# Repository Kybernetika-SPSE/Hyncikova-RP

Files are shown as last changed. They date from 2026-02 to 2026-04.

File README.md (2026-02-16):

<h1>Automatický krmič</h1><br>
<h2>Zařízení složící k pravidelnému dávkování krmiva</h2><br>
Systém kombinuje automatický režim s možností ručního ovládání pomocí tlačítek. Uživatel může ovlivnit chování zařízení podle aktuální potřeby. Během aktivního dávkování je chod signalizován LED diodou.<br>
Projekt je navržen jako základ, který lze dál upravovat a rozšiřovat podle konkrétních požadavků.<br>

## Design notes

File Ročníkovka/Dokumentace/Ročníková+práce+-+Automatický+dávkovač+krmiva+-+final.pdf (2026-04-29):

### Vyšší odborná škola a Střední průmyslová škola elektrotechnická Plzeň, Koterovská 85

## DLOUHODOBÁ ROČNÍKOVÁ PRÁCE S OBHAJOBOU

Téma: | Automatický dávkovač krmení (granulí) pro kočky
Autor práce: | Eliška HYNČÍKOVÁ
Třída: | 3. L
Vedoucí práce: | Jiří ŠVIHLA
Dne: | 30. 4. 2026

Hodnocení:

Prohlášení

Prohlašuji, že jsem tuto ročníkovou práci zpracovala samostatně a použila prameny, které uvádím v seznamu použité literatury a zdrojů informací.

Prohlašuji, že jsem nástroje UI využívala v souladu s principy akademické integrity a že na využití těchto nástrojů v práci vhodným způsobem odkazuji.

Souhlasím s využitím mé práce učiteli VOŠ a SPŠE Plzeň k výuce.

V Holýšově dne: |
Podpis: |

Poděkování

Ráda bych tímto poděkovala vedoucímu své ročníkové práce za odborné vedení, cenné rady a připomínky, které mi během zpracování práce poskytoval. Dále děkuji všem pedagogům, kteří mi v průběhu studia předávali své znalosti a podporovali mě při řešení technických i teoretických problémů.

Zvláštní poděkování patří mé rodině za trpělivost, podporu a zázemí, které mi umožnily věnovat se této práci. V neposlední řadě děkuji také všem, kteří mi jakýmkoli způsobem pomohli při realizaci projektu a přispěli k úspěšnému dokončení této ročníkové práce.

Anotace

Tato práce popisuje návrh a realizaci automatického dávkovače krmení pro kočky, který umožňuje časově řízené dávkování granulí a využívá ultrazvukový senzor k odhadu míry naplnění misky. Součástí je návrh mechaniky dávkovacího mechanismu, elektroniky s mikrokontrolérem, firmware pro plánování dávek a zpracování měření, kalibrace senzoru a experimentální ověření přesnosti i spolehlivosti zařízení.

Klíčová slova: dávkovač, kočka, ultrazvukový senzor, plánování dávek, mikrokontrolér, kybernetika

Abstract

This thesis describes the design and implementation of an automatic cat feeding dispenser that enables time-controlled dispensing of dry food and uses an ultrasonic sensor to estimate the level of food in the bowl. The work includes the design of the mechanical dispensing mechanism, the electronic system with a microcontroller, firmware for feed scheduling and measurement processing, sensor calibration, and experimental verification of the accuracy and reliability of the device.

Keywords: dispenser, cat, ultrasonic sensor, feed scheduling, microcontroller, cybernetics

Obsah

Úvod

Chov kočky domácí je v dnešní době velmi rozšířený, a to zejména v městském prostředí, kde se tento druh zvířete těší oblibě díky své relativní samostatnosti a nenáročnosti na prostor. Přesto však vyžaduje kočka pravidelnou péči, jejíž nedílnou součástí je správné a vyvážené krmení. Nedostatečná nebo naopak nadměrná dávka potravy může dlouhodobě vést ke zdravotním problémům, jako je obezita, podvýživa nebo poruchy trávení. Z těchto důvodů je důležité nejen dodržovat vhodné složení krmiva, ale také kontrolovat jeho množství a pravidelnost podávání. [1]

V současné uspěchané době však majitelé domácích mazlíčků často nemají možnost zajistit krmení v přesně stanovených časech, například z důvodu pracovního vytížení nebo delší nepřítomnosti. Jedním z možných řešení této problematiky je využití automatických dávkovačů krmiva.

Cílem této práce je proto navrhnout a zkonstruovat cenově dostupný, spolehlivý a funkční automatický dávkovač krmení pro kočku domácí. Navržené zařízení bude schopno dávkovat krmivo v předem nastavených časových intervalech a zároveň pomocí ultrazvukového senzoru odhadovat míru naplnění misky. Na základě naměřených hodnot bude systém vyhodnocovat, zda je nutné potravu ze zásobníku doplnit, nebo zda je miska stále dostatečně naplněna. Pokud měření prokáže, že kočka krmivo neodebrala v požadovaném množství, mechanismus doplnění se nespustí, čímž se zamezí zbytečnému plýtvání krmivem a přetěžování zařízení.

Práce je rozdělena na teoretickou a praktickou část. Teoretická část se zabývá principem ultrazvukového měření vzdálenosti, možnostmi dávkovacích mechanismů a základními zásadami časového řízení v automatizovaných systémech. Praktická část je zaměřena na samotný návrh řešení, konstrukci prototypu, jeho programování a následné testování funkčnosti v reálných podmínkách.

Pro výrobu byl sestaven časový plán prací Tabulka 1: Časový plán, aby samotná konstrukce a

ladění systému včetně zpracování dokumentace byla dokončena v daném termínu.

### 1. Teoretická část

Kybernetika se zaměřuje na řízení a přenos informací v systémech. Pro dávkovač krmení je klíčový uzavřený řídicí okruh: aktuátor (dávkovací mechanismus) → prostředí (granule v misce) → senzor (ultrazvuk) → měření času (RTC hodiny reálného času) →řídicí algoritmus, který dle změřeného stavu rozhoduje o dalším chování systému. [1]

Běžné konstrukce zahrnují šnekový dopravník, rotační komoru (klapku) nebo servo-řízení posuvné záklopky. Volba mechanismu ovlivňuje přesnost dávkování, riziko ucpání i nároky na napájení. Pro domácí dávkovač je vhodná rotační komora nebo šnek s krokovým motorem; pro jednodušší řešení postačí servo s dávkovací vrtulí. [1]

Ultrazvukový senzor (např. HC‑SR04/JSN‑SR04T) měří dobu letu zvukové vlny a umožňuje určit vzdálenost ke hladině granulí. Při měření v misce je nutné brát v úvahu minimální měřicí vzdálenost, kužel vyzařování a odrazy od stěn misky. Kalibrace zahrnuje mapování vzdálenosti na procento zaplnění pro konkrétní geometrii misky.

Časové dávkování lze realizovat pomocí reálného času (RTC modul, např. DS3231) nebo vnitřních

hodin mikrokontroléru. Plánování zahrnuje nastavení času, počtu dávek za den, velikosti dávky a podmínek, kdy se dávka přeskočí (např. je-li miska již plná). [3]

Konstrukce musí zamezit zranění zvířete (zakrytování pohyblivých částí), kontaminaci krmiva a zároveň umožnit snadné čištění. Elektronika má být chráněna proti prachu a granulím; napájení musí být bezpečné a spolehlivé.

### 1.1 Časový plán realizace projektu

Tabulka 1: Časový plán

Období | Plánované činnosti
listopad | Přípravná a analytická fáze • seznámení s tématem ročníkové práce, • stanovení hlavních cílů projektu, • rešerše existujících řešení automatických dávkovačů krmiva • studium principů automatizace, senzorů a časového řízení
prosinec | Návrh systému a volba součástek • návrh celkové koncepce zařízení • volba elektronických součástek • vytvoření schématu zapojení
leden | Návrh mechanických částí • tvorba 3D modelů jednotlivých mechanických částí zařízen
únor | Výroba prototypu, programování řídícího systému • příprava dat pro 3D tisk, výroba jednotlivých dílů • kontrola rozměrů a případné úpravy modelů na základě jejich funkčnosti • vytvoření řídicího programu pro mikrokontrolér
březen | Montáž zařízení a zapojení elektroniky • sestavení mechanických částí zařízení • zapojení elektronických komponent • kontrola správnosti zapojení,základní funkční testy • implementace časového řízení dávkování • práce se senzory a ladění softwaru
duben | Testování a úpravy prototypu, zpracování dokumentace a vychodnocení • testování funkčnosti zařízení v reálných podmínkách • kalibrace dávkování • odstraňování zjištěných nedostatků a zvyšování spolehlivosti zařízení • zpracování textové části ročníkové práce • doplnění obrazové dokumentace, závěrečné vyhodnocení projektu • příprava k obhajobě

### 1.2 Použité součástky a principy jejich fungování

V projektu byl jako hlavní řídicí jednotka použit mikrokontrolér Arduino Nano (viz Obrázek 1), který zajišťuje zpracování programu a řízení všech připojených komponent. Arduino vyhodnocuje vstupní data ze senzorů a na jejich základě ovládá výstupní zařízení, jako je servomotor a LED dioda. [5]

Pro sledování aktuálního času byl použit modul reálného času DS3231 RTC Module (viz Obrázek 2). Tento modul obsahuje vlastní záložní baterii, díky které si uchovává přesný čas i při odpojení napájení. V projektu slouží k tomu, aby bylo možné spouštět servomotor v pravidelných časových intervalech. [3]

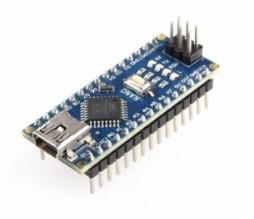
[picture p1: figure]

Obrázek 1: Mikrokontrolér Arduino Nano | Obrázek 2: Modul reálného času DS3231 RTC

K měření vzdálenosti byl použit ultrazvukový senzor HC-SR04 Ultrasonic Sensor (viz Obrázek 3).

Tento senzor pracuje na principu vysílání a přijímání ultrazvukových vln, ze kterých vypočítává

vzdálenost překážky. V rámci projektu plní bezpečnostní funkci – pokud je před senzorem

detekována překážka ve vzdálenosti menší než 13,5 cm, nedojde ke spuštění servomotoru. [2]

Jako akční člen byl použit servomotor SG90 360 degree continuous rotation servo (viz Obrázek 4)Chyba! Nenalezen zdroj odkazů., který vykonává mechanický pohyb. Servomotor se v projektu otáčí po dobu tří sekund, a to buď automaticky na základě časového signálu z RTC modulu, nebo ručně pomocí tlačítka.

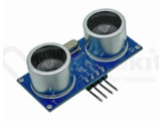
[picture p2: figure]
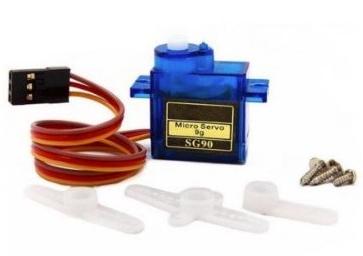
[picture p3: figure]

Obrázek 3: HC-SR04 Ultrasonic Sensor | Obrázek 4: SG90 360 degree continuous rotation servo

Součástí zapojení je také LED dioda s předřadným rezistorem (viz Obrázek 5), která slouží jako vizuální indikátor stavu zařízení. LED dioda se rozsvítí při aktivaci servomotoru a zároveň signalizuje přítomnost překážky před ultrazvukovým senzorem.

Pro ruční ovládání byl použit mikrospínač (tlačítko) (viz Obrázek 6 ), který umožňuje uživateli kdykoliv spustit servomotor nezávisle na časovém cyklu. Tato funkce neovlivňuje pravidelné časové spouštění systému.

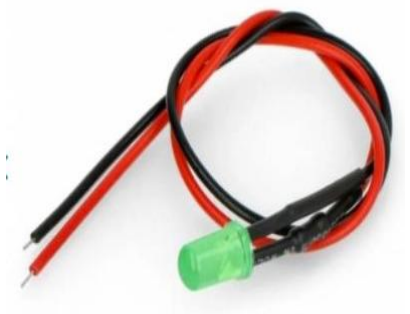
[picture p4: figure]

Obrázek 5: LED dioda s předřadným rezistorem | Obrázek 6: Mikrospínač

Jednotlivé komponenty jsou mezi sebou propojeny pomocí propojovacích vodičů typu Dupont (viz Obrázek 7), které umožňují snadné a přehledné zapojení bez nutnosti pájení. V případě použití nepájivého pole (breadboardu) bylo zapojení ještě více zjednodušeno a zpřehledněno.

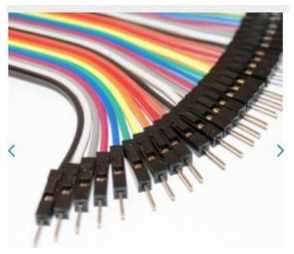
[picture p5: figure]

Obrázek 7: Vodiče typu Dupont

K napájení celého systému byla využita nabíječka do sítě universální 1x USB-A 5V/2,1A (viz Obrázek 8) a kabel USB 2.0 A, USB mini (viz Obrázek 9).

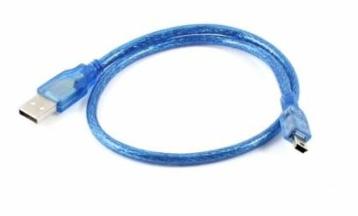
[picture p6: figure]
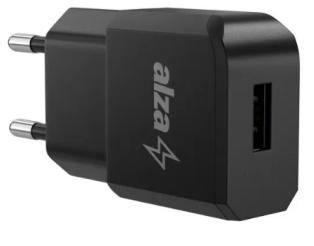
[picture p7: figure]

Obrázek 8: Nabíječka 1x USB-A 5V/2,1A | Obrázek 9: Kabel USB 2.0 A, USB mini

### 2 Praktická část

### 2.1 Architektura systému

Mikrokontrolér (Arduino), servo/krokový motor, ultrazvukový senzor (HC‑SR04), RTC (DS3231), tlačítka, LED. [3]

Požadavky:
(a) 3 naplánované dávky denně;
(b) velikost jedné dávky 40–80 g;
(c) odhad naplnění misky v krocích po 10 %;
(d) jednoduché ovládání pomocí tlačítek.
Návrh vychází z mikrokontroléru (Arduino), aktuátoru (servo), ultrazvukového senzoru (HC‑SR04), modulu RTC (DS3231), tlačítek. Napájení 5 V pro logiku a servo, RTC, ultrazvukový senzor využívá piny TRIG a ECHO, ovládání motoru přes PWM (servo). [3]

Zásobník (hopper) s objemem ~3 l, dávkovací komora s objemem jedné dávky a vodicí kanál do misky. Díly jsou navrženy pro 3D tisk (PLA/PETG) s možností demontáže pro čištění. Senzor je umístěn shora nad miskou s úhlem a vzdáleností minimalizujícími odrazy od stěn.

### 2.2 Tisk stavebních komponent

Grafické návrhy dílů byly prováděny v programu Autodesk Inventor a následně připraveny pro tisk v aplikaci PrusaSlicer - (viz Obrázek 10), (viz Obrázek 11). Samotný tisk jednotlivých stavebních komponent byl prováděn na 3D tiskárně společnosti Prusa Research CoreOne za použití PLA filamentu.

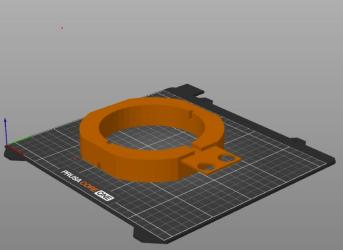
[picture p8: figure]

Obrázek 10: Box na elektrotechnika 3D model (STL) | Obrázek 11: Kruh 3D model (STL)

### 2.3 Plánovač dávek

Plánovač porovnává aktuální čas RTC s tabulkou časů (viz Tabulka 2). Dávka je spuštěna pouze tehdy, když je míra naplnění pod prahem.

Tabulka 2: Ukázkový plán dávek pro jednu kočku
Čas | Poznámka
07:30 | Snídaně
12:30 | Oběd
18:30 | Večeře

### 3 Diskuze

Při konstrukci bylo potřeba postupnou úpravou jednotlivých stavebních součástí odstranit chyby zjištěné v průběhu testování prototypu.

### 3.1 Konstrukční a mechanické úpravy dávkovacího zařízení

V průběhu konstrukce a testování prototypu dávkovacího zařízení bylo nutné postupně upravovat jednotlivé stavební součásti s cílem odstranit zjištěné mechanické a konstrukční nedostatky. Jedním z klíčových problémů byla volba optimální šíře dávkovací vrtule, která musela být navržena tak, aby granule nepropadávaly kolem dávkovacího mechanismu do boxu s elektronikou. Současně bylo nutné přepracovat držák vrtule a servomotoru, jelikož původní řešení nezajišťovalo dostatečnou oporu a docházelo k jeho prohýbání, což mělo za následek posun dávkovacího mechanismu.

Další oblastí úprav bylo stanovení ideálního sklonu nakloněné roviny, po které jsou granule z dávkovacího zařízení vedeny do misky. Nesprávný sklon negativně ovlivňoval plynulost sypání krmiva. Konstrukčně vhodná se tedy jeví až čtvrtá varianta boxu na elektroniku.

Při testování prvních prototypů se rovněž ukázalo, že dávkovací vrtule není při vyšším zatížení granulemi dostatečně pevná a docházelo k jejímu rozlamování. Z tohoto důvodu bylo nutné vrtuli konstrukčně zesílit, aby vyhovovala požadovanému zatížení.

Mezi další mechanické nedostatky patřila netěsnost v přechodu mezi zásobníkem a dávkovací komorou s vrtulí. Vlivem této netěsnosti docházelo k samovolnému propadávání granulí do boxu s elektrotechnikou, což představovalo riziko poškození elektronických součástí. Stabilita zařízení byla rovněž ovlivněna kývajícím se zásobníkem na suché krmivo, což bylo vyřešeno zvětšením stěn držáku vrtule a servomotoru. Problémy se objevily také u senzoru, který nebyl v držáku dostatečně pevně fixován. Při manipulaci se zařízením mohlo docházet k jeho mikroposunu, což vedlo k chybným odrazům světla od misky a následnému zastavení dávkovacího mechanismu.

### 3.2 Výrobní, montážní a provozní komplikace včetně elektroniky a softwaru

Kromě konstrukčních úprav se během realizace prototypu objevila řada problémů spojených s výrobou, montáží a provozem zařízení. Vzhledem k tiskovým odchylkám při 3D tisku docházelo při kompletaci k potížím se sesazováním jednotlivých dílů, zejména v případě zásobníku a jeho poklopu, kde nebyly dilatace navrženy dostatečně velké.

Problematické bylo rovněž přesné nastavení velikosti otvoru v ose vrtule určeného pro nasazení na servomotor, jelikož bylo obtížné zohlednit tiskové tolerance tak, aby otvor ideálně odpovídal požadovanému průměru. Výtisk použitelný pro pohyblivý mechanismu vrtule je tedy až šestým v pořadí.

Výrobu komplikovalo také obtížné odstraňování tiskových podpor u některých součástí, což zvyšovalo časovou náročnost dokončovacích prací a riziko poškození dílů.

Při osazování vnějšího pláště boxu na elektrotechniku se objevil problém s fixací tlačítka a LED diody, který byl nakonec úspěšně vyřešen použitím mosgumy jako tlumicího a fixačního materiálu.

Vedle mechanických a výrobních potíží se objevily také komplikace v oblasti softwaru. Při psaní kódu byly zaznamenány neviditelné mezery, které způsobovaly vznik chyb a následná chybová hlášení systému, což ztěžovalo ladění programu.

V neposlední řadě se během jednotlivých konstrukčních kroků objevoval i lidský faktor v podobě klesající motivace odstraňovat postupně se objevující nedostatky, což poukazuje na náročnost vývoje prototypového zařízení.

Závěr

Byl navržen, realizován a odzkoušen funkční prototyp automatického dávkovače krmiva s časově řízeným dávkováním a kontrolou naplnění misky pomocí ultrazvukového senzoru. Práce se zaměřila na komplexní návrh zařízení od volby vhodných komponent přes konstrukci mechanické části a zapojení elektroniky až po tvorbu řídicího firmware mikrokontroléru. Výsledné řešení slouží jako základní platforma pro další technický rozvoj systému.

Praktické ověření prototypu prokázalo, že navržená koncepce je funkční a z hlediska provozu použitelná, přičemž splňuje základní požadavky na automatizované krmení domácích zvířat. Zařízení je schopno spolehlivě dávkovat krmivo v nastavených časových intervalech a současně vyhodnocovat stav misky, čímž přispívá k pravidelnému a kontrolovanému krmení.

Součástí řešení bylo rovněž vytvoření a experimentální ověření kalibračních postupů, které umožňují přizpůsobit převodní charakteristiku ultrazvukového měření různým typům a velikostem misek. Tím se zvyšuje univerzálnost zařízení a jeho použitelnost v různých provozních podmínkách. Implementovaný firmware zajišťuje základní logiku řízení dávkování a správnou spolupráci jednotlivých hardwarových prvků.

Testování ukázalo, že ultrazvukové měření je při vhodném umístění senzoru dostatečně spolehlivé, avšak je citlivé na tvar misky a nežádoucí odrazy, které mohou zvyšovat chybu měření. Z hlediska dávkovacího mechanismu byla posouzena dávkovací vrtule jako konstrukčně jednodušší řešení s větší variabilitou dávky a dávkovací šnek jako přesnější, avšak energeticky i výrobně náročnější alternativa.

Navržený prototyp představuje otevřený a rozšiřitelný základ pro další vývoj. Mezi perspektivní směry patří zejména doplnění váhového senzoru pro přesnější kontrolu skutečně vydané dávky krmiva, vytvoření mobilní aplikace umožňující vzdálené nastavení a monitoring zařízení a implementace zálohovaného napájení pro zajištění provozu při výpadku elektrické sítě. Uvedená vylepšení by dále zvýšila přesnost dávkování, spolehlivost systému a celkový uživatelský komfort.

Seznam obrázků

Obrázek 1: Mikrokontrolér Arduino Nano | 9
Obrázek 2: Modul reálného času DS3231 RTC | 9
Obrázek 3: HC-SR04 Ultrasonic Sensor | 10
Obrázek 4: SG90 360 degree continuous rotation servo | 10
Obrázek 5: LED dioda s předřadným rezistorem | 10
Obrázek 6: Mikrospínač | 10
Obrázek 7: Vodiče typu Dupont | 11
Obrázek 8: Nabíječka 1x USB-A 5V/2,1A | 11
Obrázek 9: Kabel USB 2.0 A, USB mini | 11
Obrázek 10: Box na elektrotechnika 3D model (STL) | 12
Obrázek 11: Kruh 3D model (STL) | 12

Seznam tabulek

Tabulka 1: Časový plán | 8
Tabulka 2: Ukázkový plán dávek pro jednu kočku | 13

Seznam použité literatury

[1] OGATA, Katsuhiko. Modern Control Engineering. 5th ed. Upper Saddle River: Prentice

Hall, 2010. ISBN 978-0136156734.

[2] AOSONG. HC-SR04 Ultrasonic Ranging Module Datasheet [online]. [cit. 2026-04-28].

Dostupné z: https://cdn.sparkfun.com/datasheets/Sensors/Proximity/HCSR04.pdf

[3] MAXIM INTEGRATED. DS3231 Extremely Accurate I²C-Integrated RTC Datasheet

[online]. [cit. 2026-04-28]. Dostupné z:

https://datasheets.maximintegrated.com/en/ds/DS3231.pdf

[4] Drátek.cz. Fotografie elektronických komponent (např. HC-SR04, ESP32 moduly) [online].

[cit. 2026-04-28]. Dostupné z: https://www.dratek.cz/

[5] LáskaKit.cz. Návody a zapojení elektronických obvodů [online]. [cit. 2026-04-28]. Dostupné

z: https://www.laskakit.cz/

[6] Canva. Grafický nástroj pro úpravu obrázků [online]. [cit. 2026-04-28]. Dostupné z:

https://www.canva.com/

[7] OPENAI. ChatGPT [online]. [cit. 2026-04-28]. Dostupné z: https://chatgpt.com/

Seznam příloh

Příloha I: Výkresy - Poklop
Příloha II: Výkresy - Zásobník
Příloha III: Výkresy – Miska
Příloha IV: Výkresy – Držák vrtule a motoru Příloha V: Výkresy – Vrtule
Příloha VI: Výkresy – Box na elektroniku Příloha VI: Výkresy – Box na elektroniku Příloha VII: Výkresy - Roh
Příloha VIII: Výkresy - Kruh
Příloha IX: Výkresy – Víko senzoru
Příloha X: Seznam komponent – mechanické součásti Příloha XI: Ukázka prostředí kódu
Příloha XII: Schéma zapojení krmiče
Příloha XIII: Fotografie prototypu

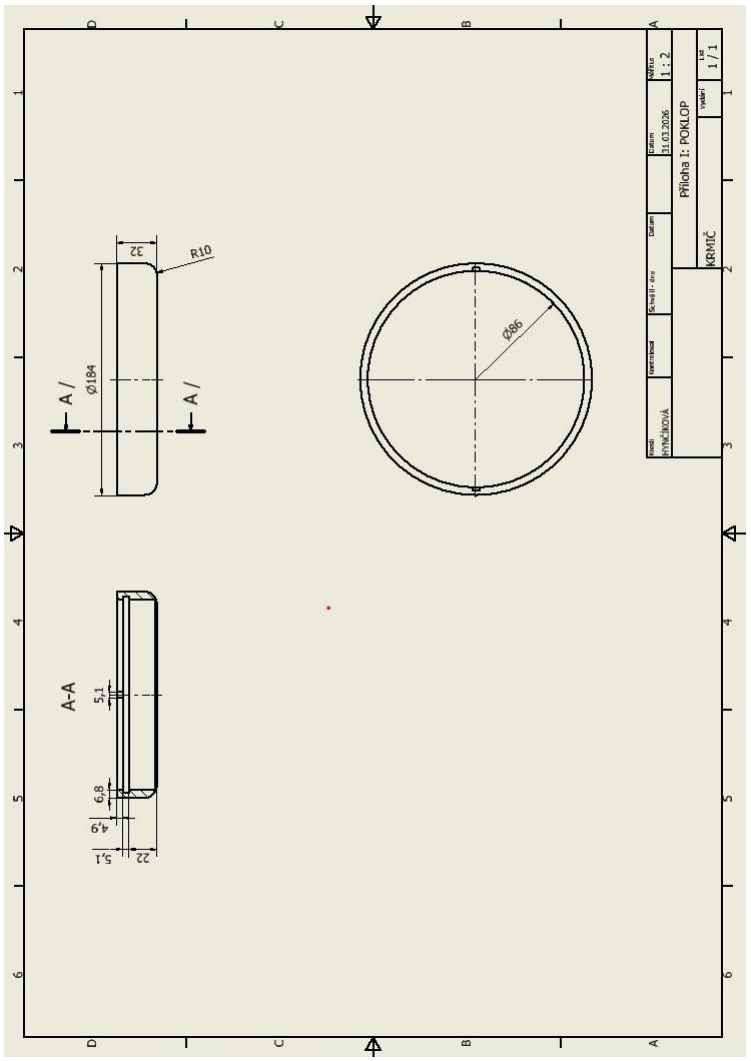
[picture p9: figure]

I

Příloha I: Výkresy – Poklop

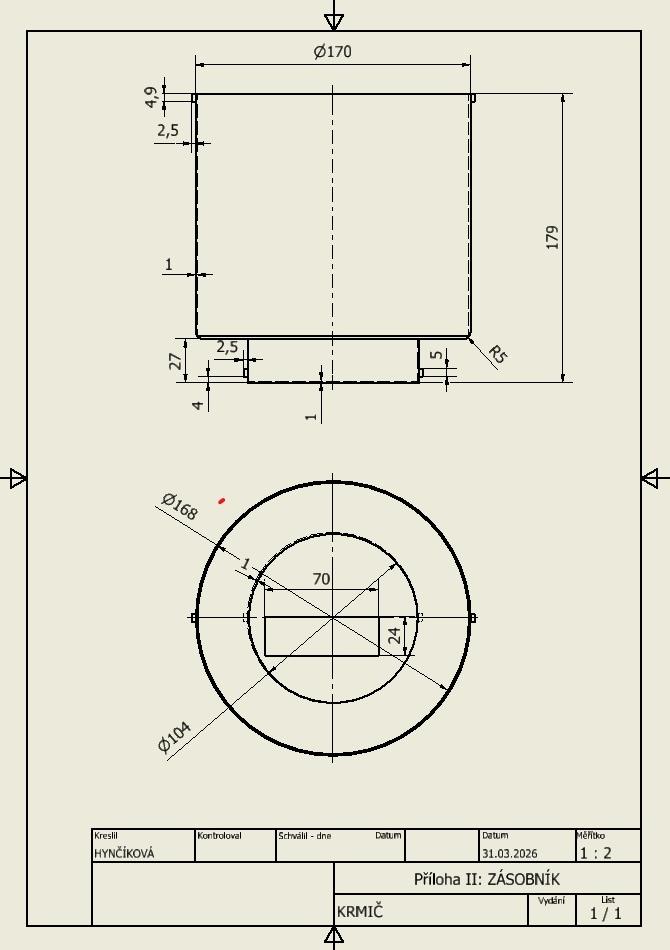
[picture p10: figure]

II

Příloha II: Výkresy - Zásobník

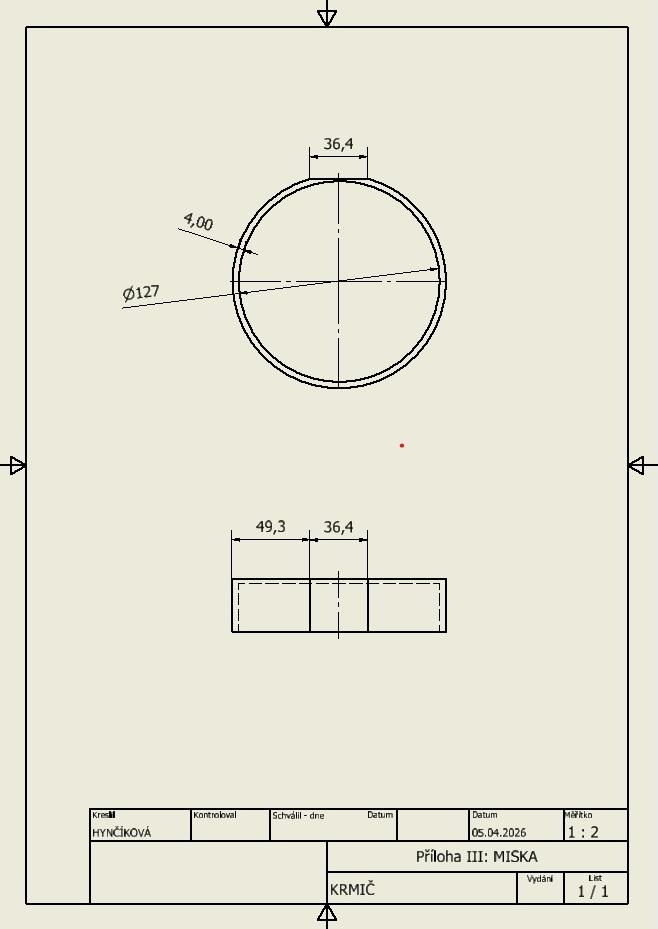
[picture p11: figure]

III

Příloha III: Výkresy - Miska

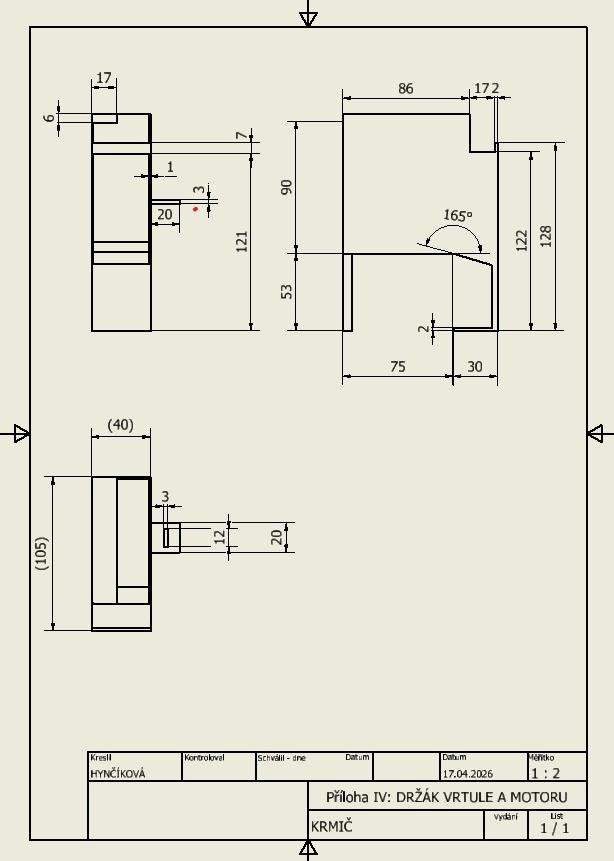
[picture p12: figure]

IV

Příloha IV: Výkresy – Držák vrtule a servomotoru

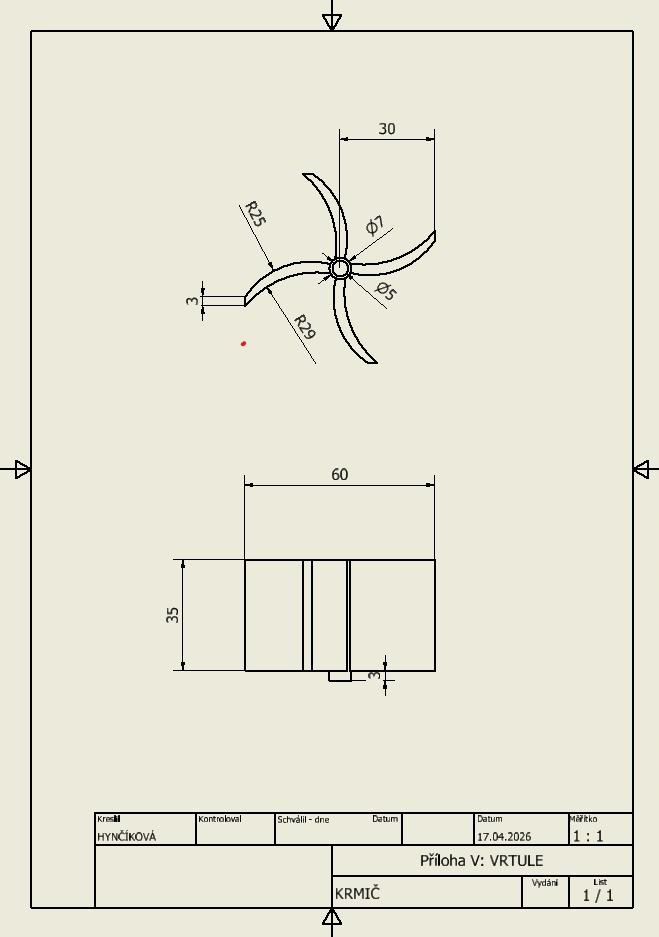
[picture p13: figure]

V

Příloha V: Výkresy- Vrtule

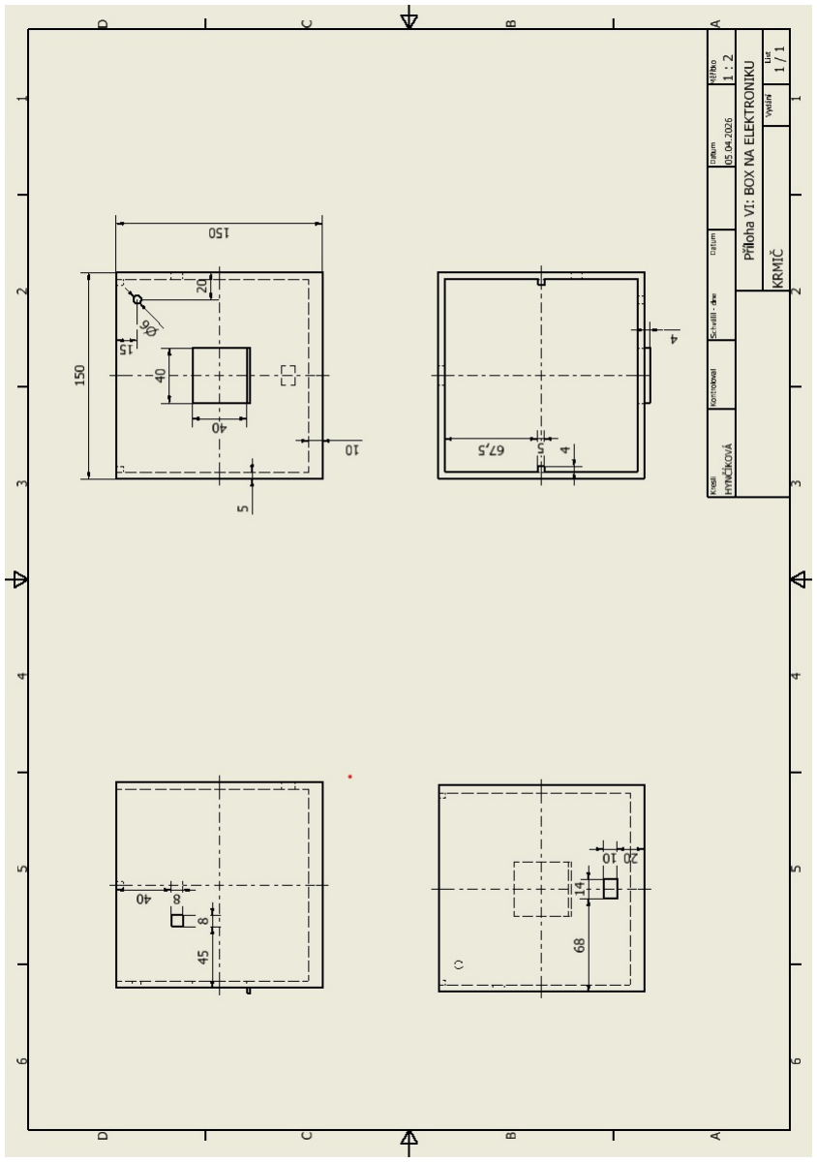
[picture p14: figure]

VI

Příloha VI: Výkresy/3D model dílů (STL) – Box na elektroniku

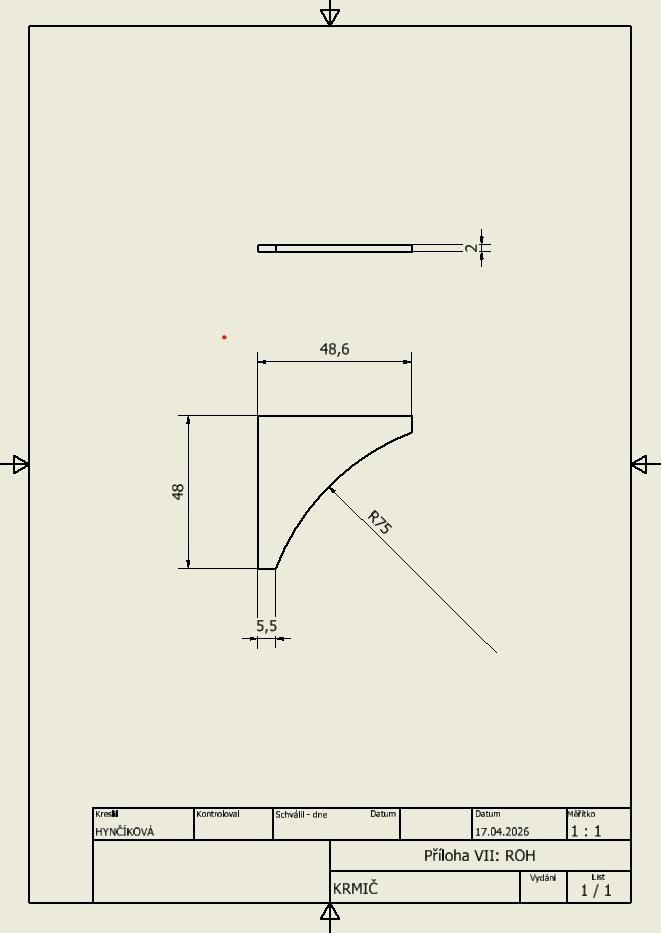
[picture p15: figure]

VII

Příloha VII: Výkresy/3D model dílů (STL) – Roh

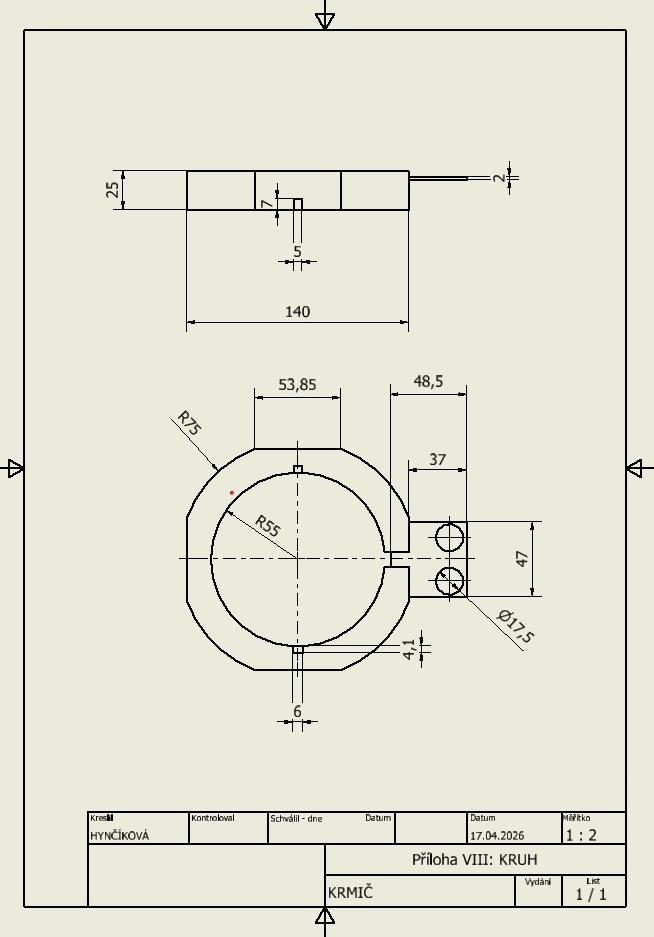
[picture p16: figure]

VIII

Příloha VIII: Výkresy/3D model dílů (STL) - Kruh

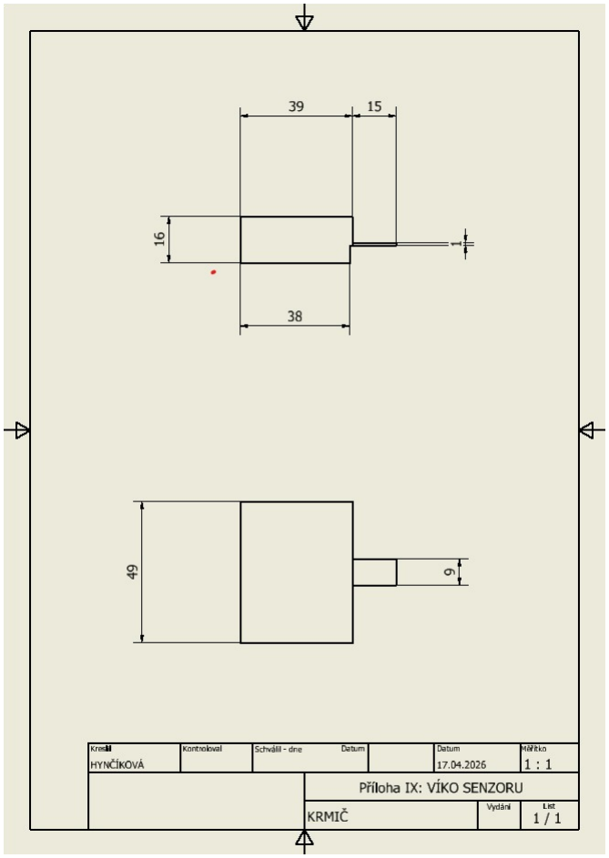
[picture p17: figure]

IX

Příloha IX: Výkresy/3D model dílů (STL) – Víko senzoru

X

Příloha X: Seznam komponent – mechanické součásti

Stavební komponenty

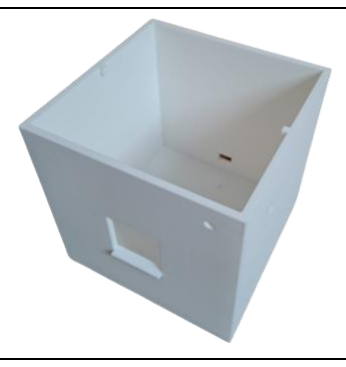
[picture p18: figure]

Box na elektrotechniku

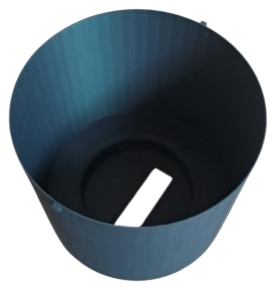
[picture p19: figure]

Zásobník

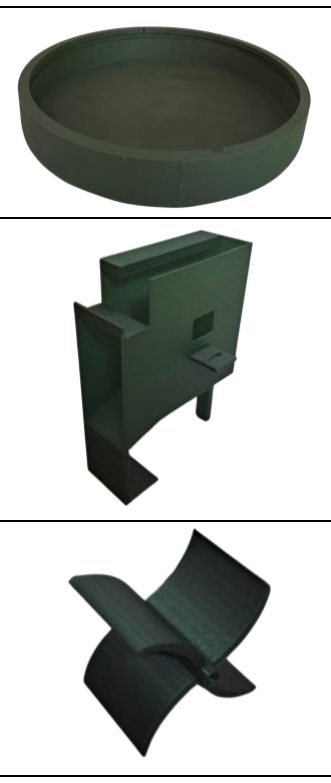
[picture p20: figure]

Poklop

Držák vrtule a servomotoru

Vrtule

XI

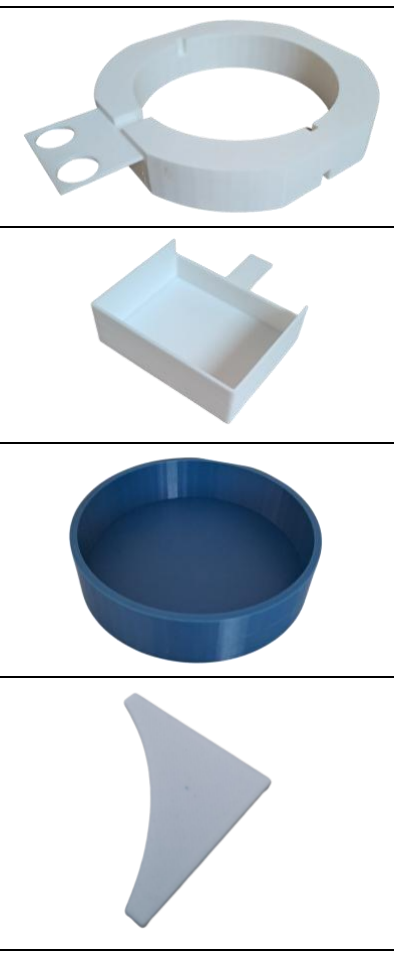
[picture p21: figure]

Kruh

Víko senzoru

Miska

Roh

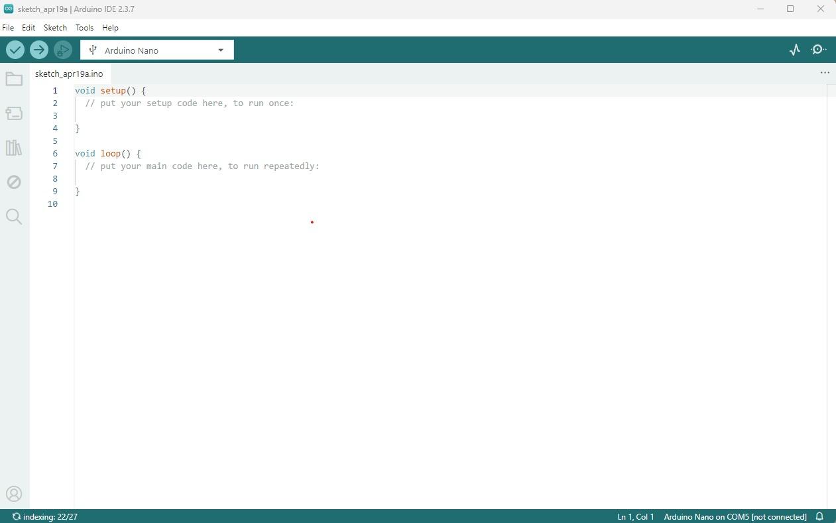
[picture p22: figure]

XII

Příloha XI: Ukázka prostředí kódu

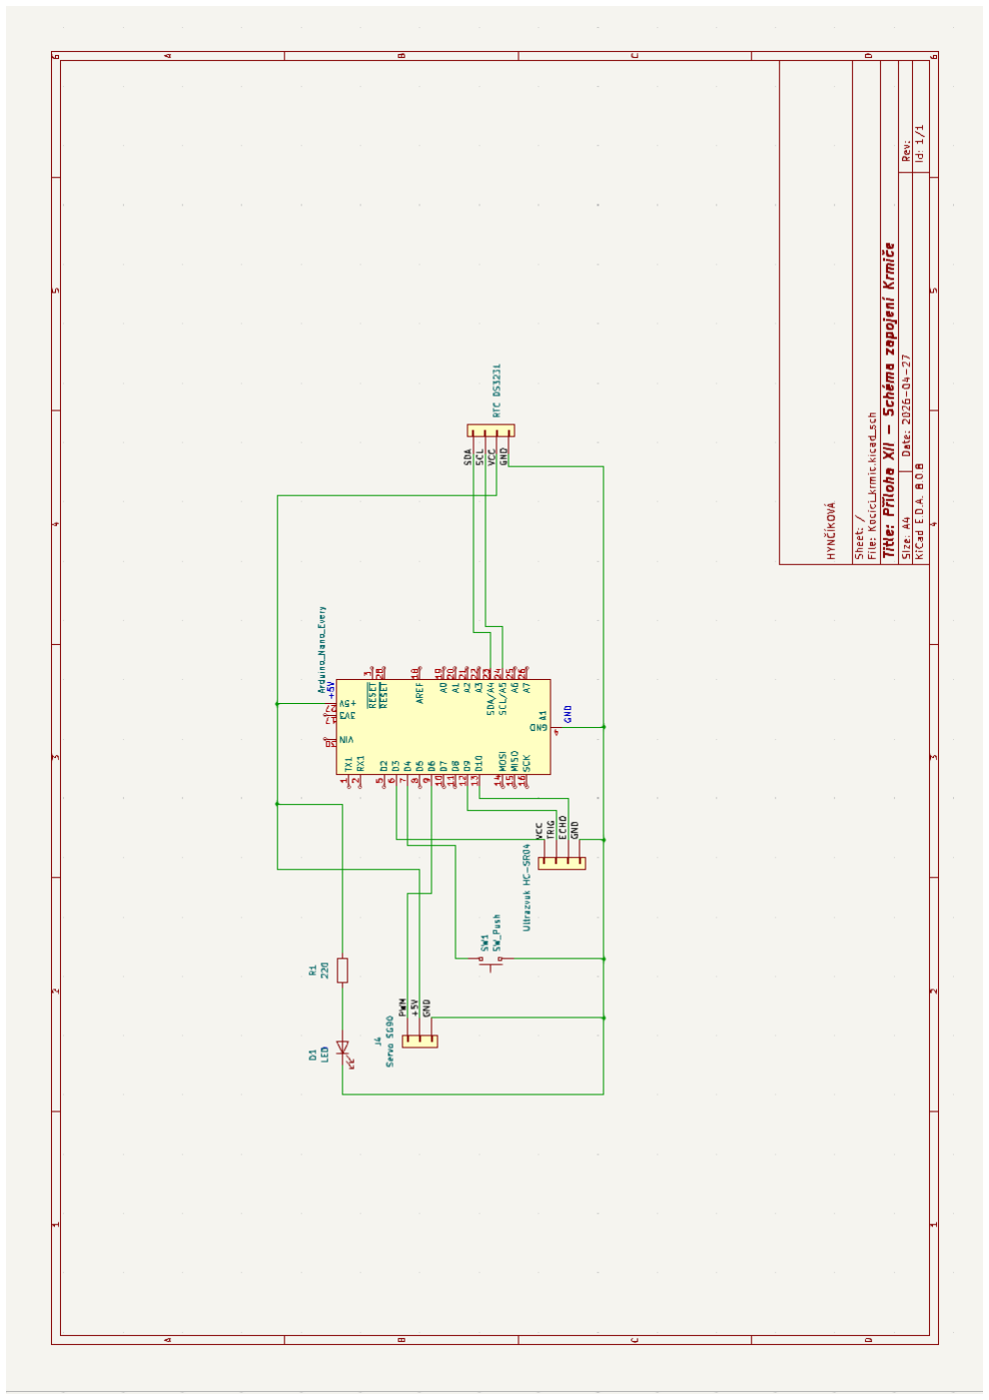
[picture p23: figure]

XIII

Příloha XII: Schéma zapojení krmiče

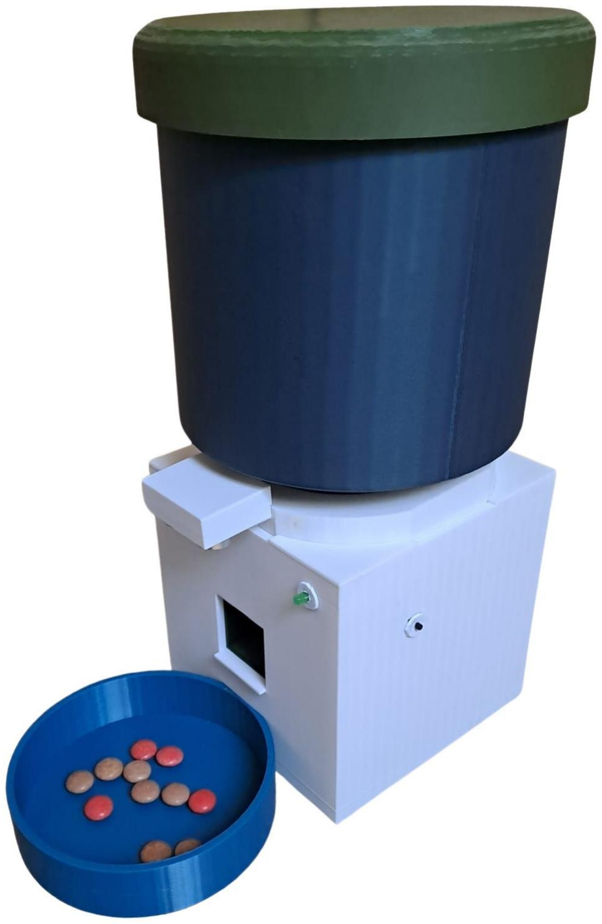
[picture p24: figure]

XIV

Příloha XIII Fotografie prototypu

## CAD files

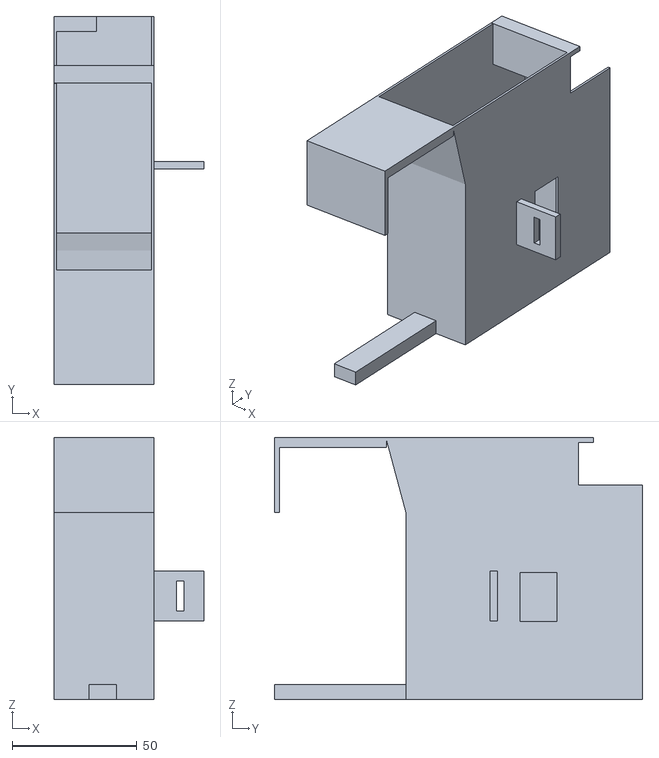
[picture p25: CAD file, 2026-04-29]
Ročníkovka/Součástky/Na servo.stl
60.0 x 147.8 x 105.1

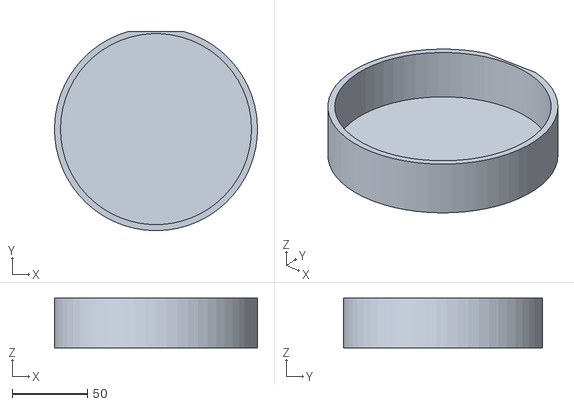
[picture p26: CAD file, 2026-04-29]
Ročníkovka/Součástky/Miska.stl
135.0 x 132.5 x 33.0

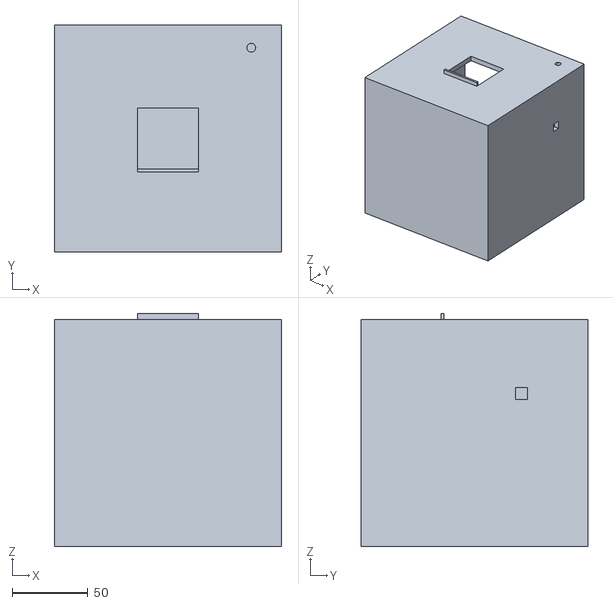
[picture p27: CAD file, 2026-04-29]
Ročníkovka/Součástky/Box na elektro.stl
150.0 x 150.0 x 154.0

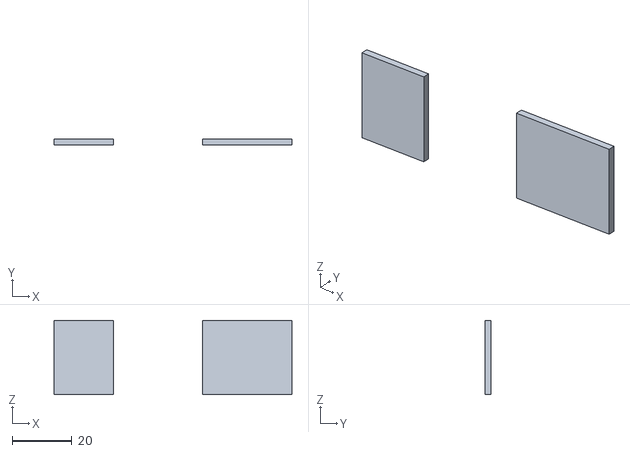
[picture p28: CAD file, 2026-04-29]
Ročníkovka/Součástky/Krytka.stl
80.0 x 2.00 x 25.0

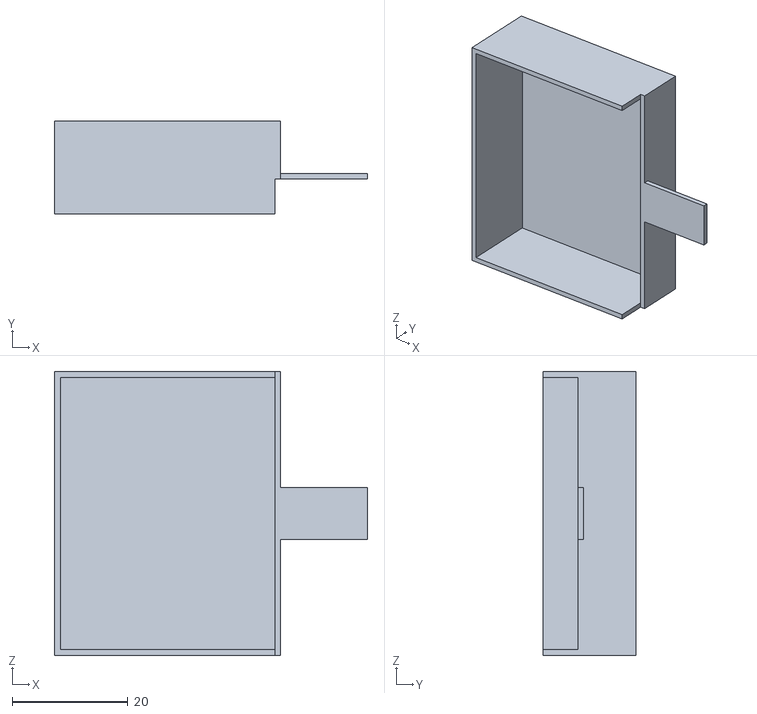
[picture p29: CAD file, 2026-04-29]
Ročníkovka/Součástky/Víko senzor.stl
54.0 x 16.0 x 49.0

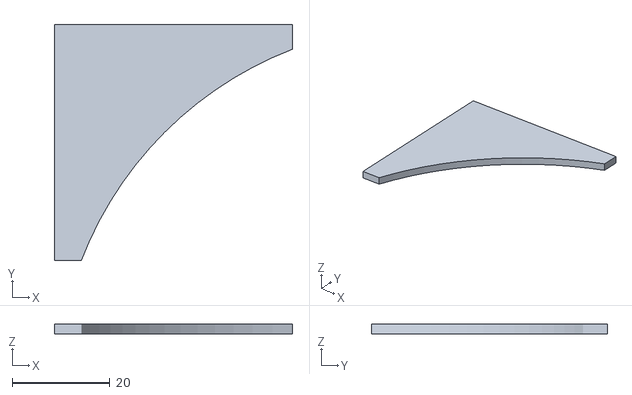
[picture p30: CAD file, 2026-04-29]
Ročníkovka/Součástky/Roh.stl
48.6 x 48.1 x 2.00

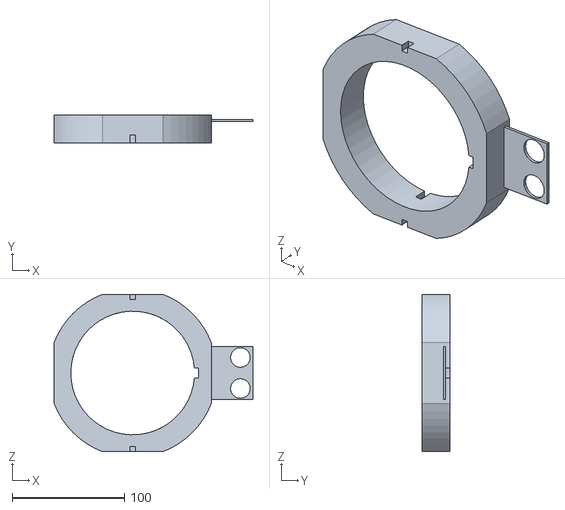
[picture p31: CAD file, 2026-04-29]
Ročníkovka/Součástky/Kruh.stl
177.0 x 25.0 x 140.0

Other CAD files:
Ročníkovka/Součástky/Box na elektro.idw
Ročníkovka/Součástky/Box na elektro.ipt
Ročníkovka/Součástky/Kruh.idw
Ročníkovka/Součástky/Kruh.ipt
Ročníkovka/Součástky/Krytka.ipt
Ročníkovka/Součástky/Miska.idw
Ročníkovka/Součástky/Miska.ipt
Ročníkovka/Součástky/Na servo.idw
Ročníkovka/Součástky/Na servo.ipt
Ročníkovka/Součástky/Naběračka1.idw
Ročníkovka/Součástky/Poklop.idw
Ročníkovka/Součástky/Roh.idw
Ročníkovka/Součástky/Roh.ipt
Ročníkovka/Součástky/Víko senzor.idw
Ročníkovka/Součástky/Víko senzor.ipt
Ročníkovka/Součástky/Zásobník oprava.idw

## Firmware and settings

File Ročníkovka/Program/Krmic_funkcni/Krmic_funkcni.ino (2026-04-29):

#include <Wire.h>
#include <RTClib.h>
#include <Servo.h>

RTC_DS3231 rtc;
Servo servoMotor;

#define trigPin 9
#define echoPin 10
#define ledPin 3
#define buttonPin 4

long duration;
float distance;

int lastRunMinute = -1;
int lastRunHour = -1;

bool buttonWasPressed = false;

// -------- Ultrazvuk --------
float zmerVzdalenost() {
  digitalWrite(trigPin, LOW);
  delayMicroseconds(2);

  digitalWrite(trigPin, HIGH);
  delayMicroseconds(10);
  digitalWrite(trigPin, LOW);

  duration = pulseIn(echoPin, HIGH, 30000);
  return duration * 0.034 / 2;
}

// -------- Servo --------
void otocServo() {
  digitalWrite(ledPin, HIGH);

  servoMotor.write(75);   // pomalejší otáčení
  delay(3000);

  servoMotor.write(90);   // stop
}

// -------- Setup --------
void setup() {
  Serial.begin(9600);
  Wire.begin();
  rtc.begin();

  pinMode(trigPin, OUTPUT);
  pinMode(echoPin, INPUT);
  pinMode(ledPin, OUTPUT);
  pinMode(buttonPin, INPUT_PULLUP);

  servoMotor.attach(6);
  servoMotor.write(90);
}

// -------- Loop --------
void loop() {

  DateTime now = rtc.now();
  int hourNow = now.hour();
  int minuteNow = now.minute();

  distance = zmerVzdalenost();

  Serial.print("Cas: ");
  Serial.print(hourNow);
  Serial.print(":");
  Serial.print(minuteNow);
  Serial.print(" | Vzdalenost: ");
  Serial.println(distance);

  bool prekazka = (distance > 0 && distance < 13.5);

  // -------- TLAČÍTKO --------
  bool buttonPressed = (digitalRead(buttonPin) == LOW);
  if (buttonPressed && !buttonWasPressed) {
    Serial.println("Tlacitko zmacknuto");
    otocServo();
  }
  buttonWasPressed = buttonPressed;

  // -------- KONKRÉTNÍ ČASY --------
  bool jeCas =
    (hourNow == 7  && minuteNow == 0) ||
    (hourNow == 12 && minuteNow == 30) ||
    (hourNow == 18 && minuteNow == 30);

  if (jeCas && !(hourNow == lastRunHour && minuteNow == lastRunMinute)) {

    if (prekazka) {
      Serial.println("Preskoceno kvuli prekazce");
    } else {
      Serial.println("Servo podle konkretniho casu");
      otocServo();
    }

    lastRunHour = hourNow;
    lastRunMinute = minuteNow;
  }

  // -------- LED --------
  if (prekazka) {
    digitalWrite(ledPin, HIGH);
  } else {
    digitalWrite(ledPin, LOW);
  }

  delay(100);
}

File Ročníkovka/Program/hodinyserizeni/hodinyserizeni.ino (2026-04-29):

#include <Wire.h>
#include <RTClib.h>

RTC_DS3231 rtc;

void setup () {
  Serial.begin(9600);

  if (!rtc.begin()) {
    Serial.println("RTC nenalezeno!");
    while (1);
  }

  // Nastaví čas podle počítače (čas při kompilaci)
  rtc.adjust(DateTime(F(__DATE__), F(__TIME__)));

  Serial.println("Cas byl nastaven!");
}

void loop () {
  // nic se neděje
}

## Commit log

2026-01-01 Součástky krmiče
    [Box na elektrotechniku oprava.ipt, Miska.ipt, Naběračka.ipt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]
2026-01-15 Nákresy
    [Box na elektrotechniku oprava.ipt, Miska.ipt, Naběračka.ipt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]
